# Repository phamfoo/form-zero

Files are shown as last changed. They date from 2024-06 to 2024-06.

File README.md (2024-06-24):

# Form Zero
> Gasket mounted ortholinear keyboard

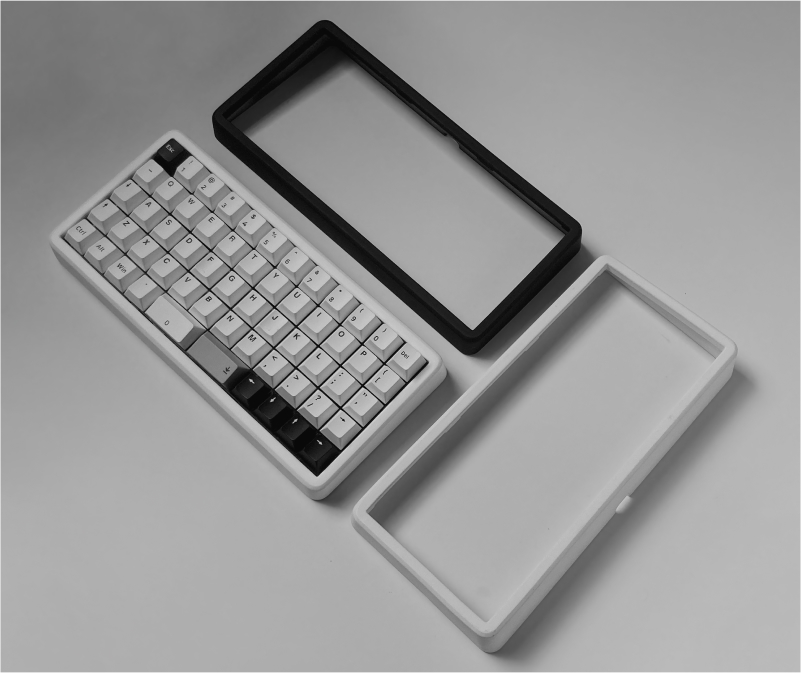
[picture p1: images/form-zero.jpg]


## Introduction
This project aims to provide an ergonomic keyboard that looks nice while also including the neat features that you'd find in custom mechanical keyboards:

- Gasket-mounted.
- Hotswap PCB.
- Clean and minimal design.

It's also designed to be put together by hobbyists, so all the parts can be easily sourced and only basic soldering skills are required.

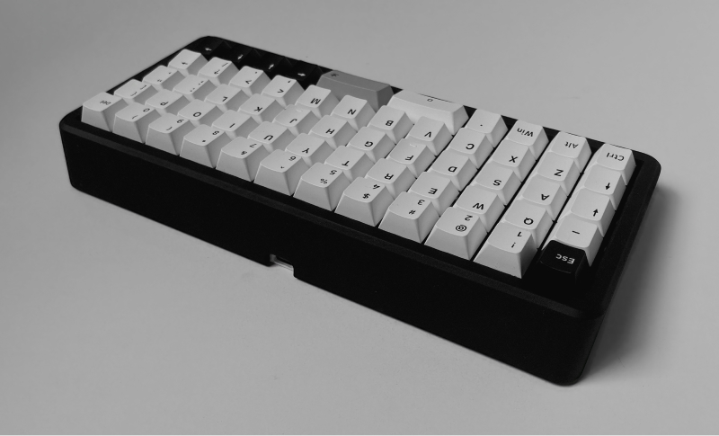
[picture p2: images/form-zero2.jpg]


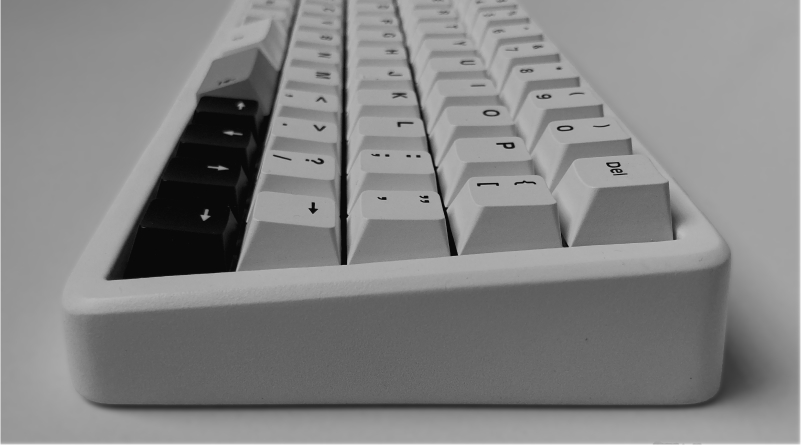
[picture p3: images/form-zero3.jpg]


## Build guide
See [build](/build)

## Thanks
[JLCPCB](https://jlcpcb.com/) for providing the keyboard plate, 3D printed case, and PCBs for this project. If you're looking to build your own board, I highly recommend their services.

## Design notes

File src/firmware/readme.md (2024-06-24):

# form_zero

form_zero

*A short description of the keyboard/project*

* Keyboard Maintainer: [Tien Pham](https://github.com/phamfoo)
* Hardware Supported: *The PCBs, controllers supported*
* Hardware Availability: *Links to where you can find this hardware*

Make example for this keyboard (after setting up your build environment):

    make form_zero:default

Flashing example for this keyboard:

    make form_zero:default:flash

See the [build environment setup](https://docs.qmk.fm/#/getting_started_build_tools) and the [make instructions](https://docs.qmk.fm/#/getting_started_make_guide) for more information. Brand new to QMK? Start with our [Complete Newbs Guide](https://docs.qmk.fm/#/newbs).

## Bootloader

Enter the bootloader in 3 ways:

* **Bootmagic reset**: Hold down the key at (0,0) in the matrix (usually the top left key or Escape) and plug in the keyboard
* **Physical reset button**: Briefly press the button on the back of the PCB - some may have pads you must short instead
* **Keycode in layout**: Press the key mapped to `QK_BOOT` if it is available

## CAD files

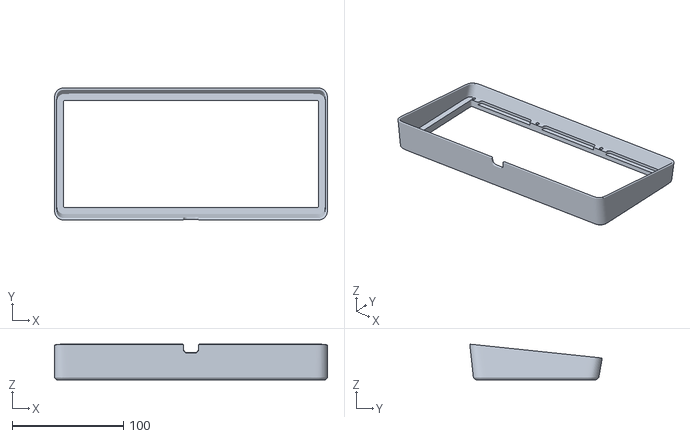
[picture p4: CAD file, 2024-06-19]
build/cases/fdm-top-case.stl
245.7 x 119.1 x 32.1

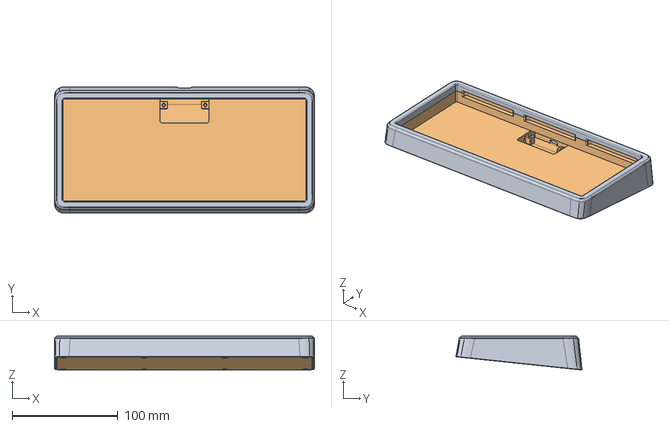
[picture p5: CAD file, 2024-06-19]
src/cases/resin-case.step
245.6 x 119.1 x 32.1 mm

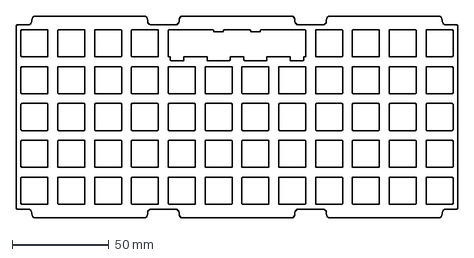
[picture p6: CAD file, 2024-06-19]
src/plates/plate.dxf
228.6 x 104.3 mm

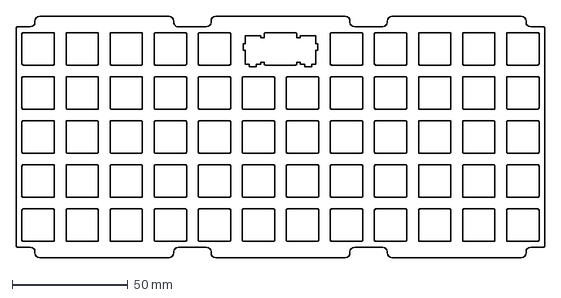
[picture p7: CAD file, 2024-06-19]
src/plates/plate-59.dxf
228.6 x 104.3 mm

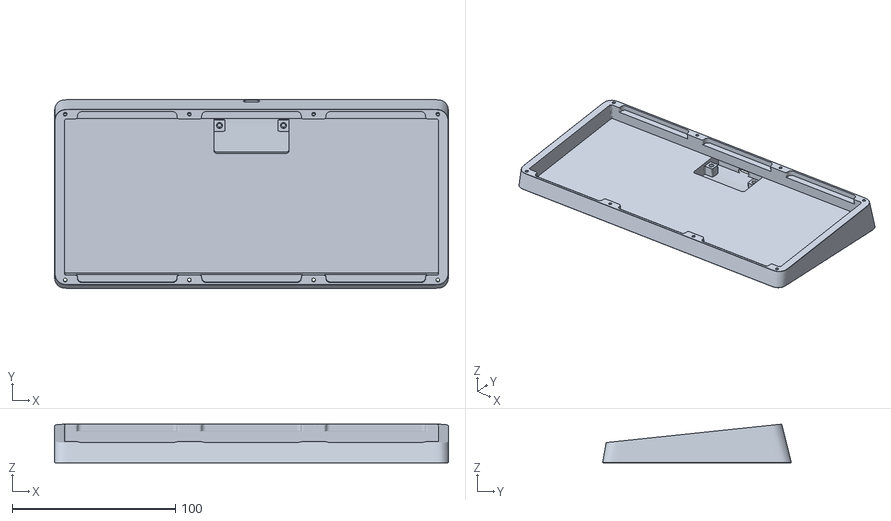
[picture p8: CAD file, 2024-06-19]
build/cases/resin-bottom-case.stl
241.6 x 115.7 x 23.7

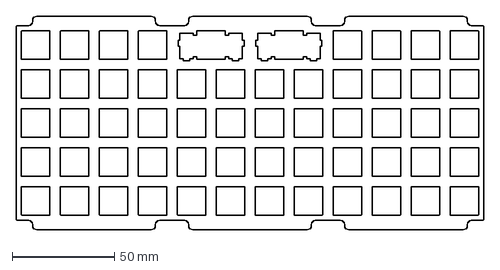
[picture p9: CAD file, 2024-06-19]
src/plates/plate-58.dxf
228.6 x 104.3 mm

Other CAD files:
build/cases/resin-top-case.stl
src/cases/fdm-case.step
build/cases/fdm-bottom-case.stl

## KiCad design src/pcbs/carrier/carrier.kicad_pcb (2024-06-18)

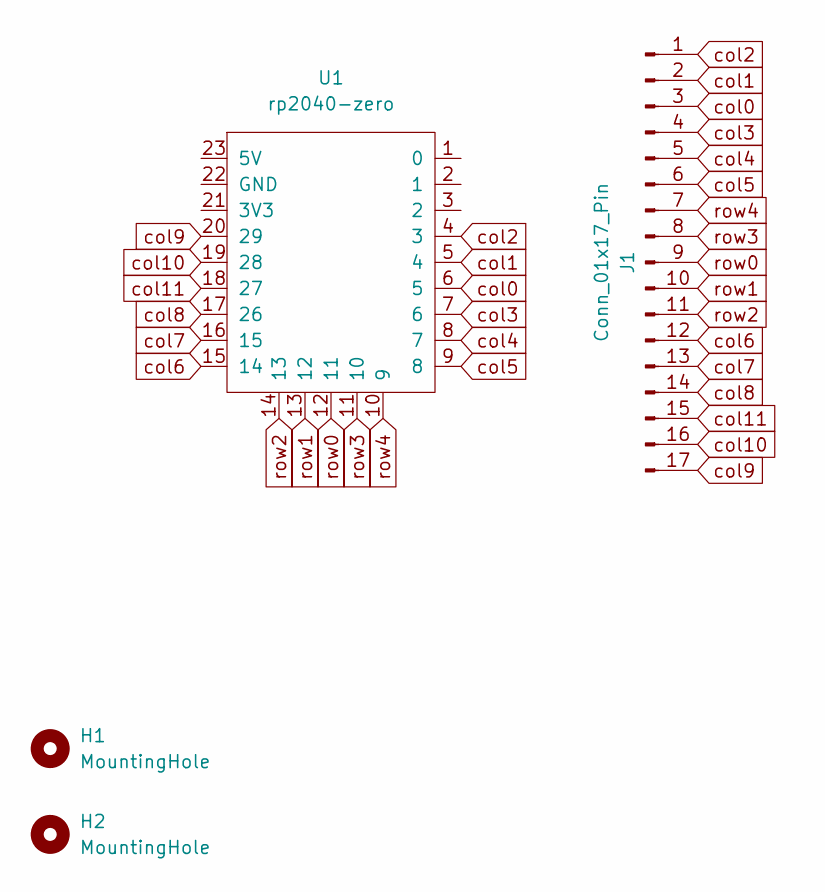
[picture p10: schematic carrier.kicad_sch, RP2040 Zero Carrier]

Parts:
H1, H2: MountingHole; MountingHole_2.2mm_M2
J1: Conn_01x17_Pin; PinHeader_1x17_P2.54mm_Vertical
U1: rp2040-zero; rp2040-zero-tht

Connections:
col0: J1.3, U1.6 (5)
col1: J1.2, U1.5 (4)
col2: J1.1, U1.4 (3)
col3: J1.4, U1.7 (6)
col4: J1.5, U1.8 (7)
col5: J1.6, U1.9 (8)
col6: J1.12, U1.15 (14)
col7: J1.13, U1.16 (15)
col8: J1.14, U1.17 (26)
col9: J1.17, U1.20 (29)
col10: J1.16, U1.19 (28)
col11: J1.15, U1.18 (27)
row0: J1.9, U1.12 (11)
row1: J1.10, U1.13 (12)
row2: J1.11, U1.14 (13)
row3: J1.8, U1.11 (10)
row4: J1.7, U1.10 (9)

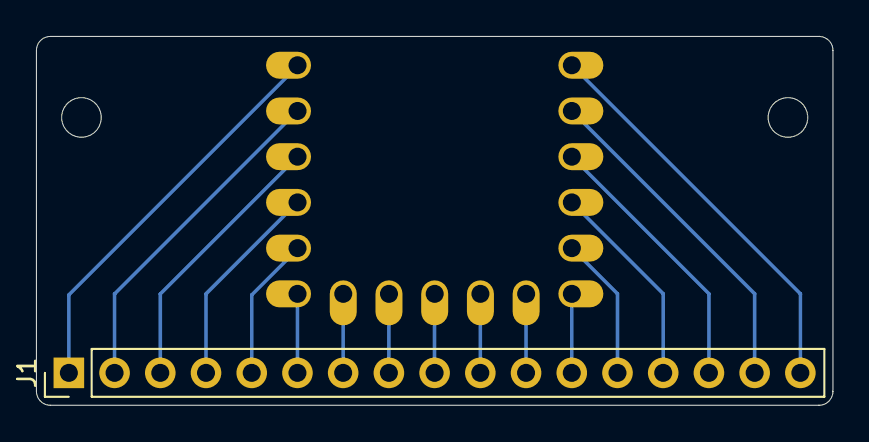
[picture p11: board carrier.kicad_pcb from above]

Board: 2 copper layers, 44.2 x 20.5 mm, 4 parts (1 on the bottom side), 17 nets.

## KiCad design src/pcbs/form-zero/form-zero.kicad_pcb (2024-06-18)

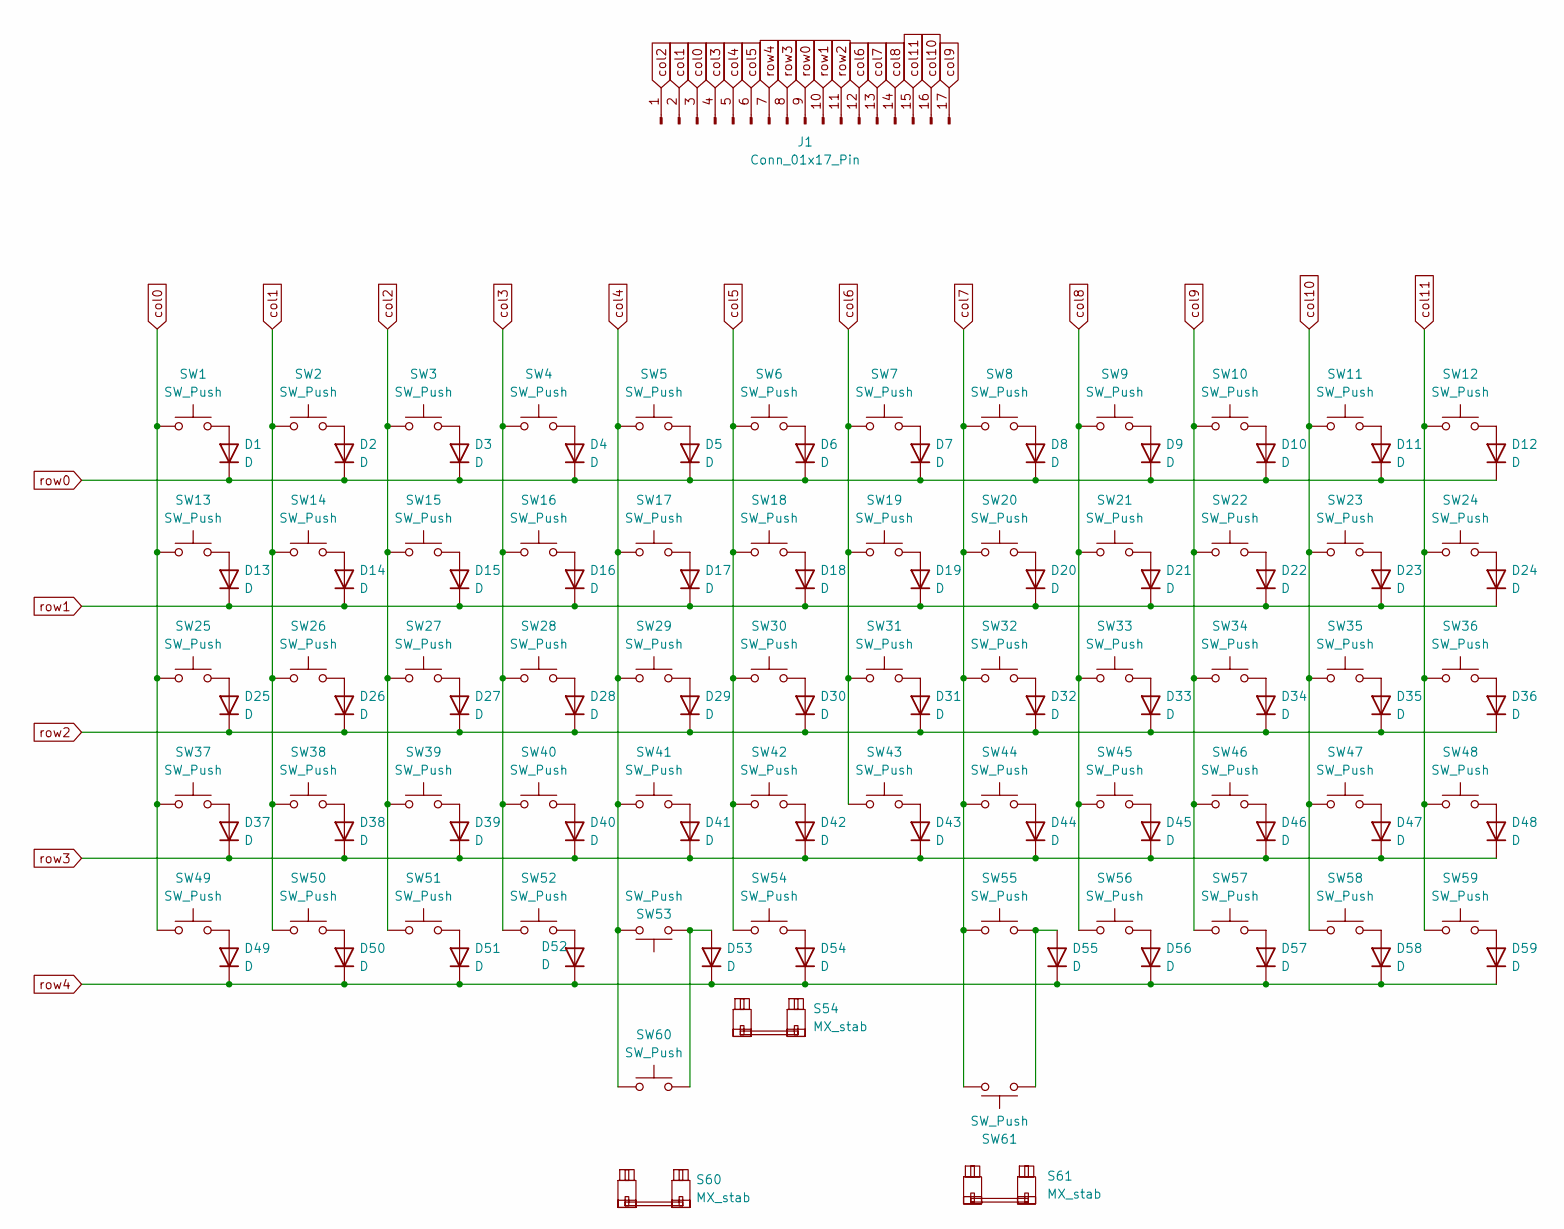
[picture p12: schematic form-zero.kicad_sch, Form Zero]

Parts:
D1, D2, D3, D4, D5, D6, D7, D8, D9, D10, D11, D12, D13, D14, D15, D16, D17, D18, D19, D20, D21, D22, D23, D24, D25, D26, D27, D28, D29, D30, D31, D32, D33, D34, D35, D36, D37, D38, D39, D40, D41, D42, D43, D44, D45, D46, D47, D48, D49, D50, D51, D52, D53, D54, D55, D56, D57, D58, D59: D; D3_TH_SMD_v2
J1: Conn_01x17_Pin; PinHeader_1x17_P2.54mm_Vertical
S54, S60, S61: MX_stab; STAB_MX_2u
SW1, SW2, SW3, SW4, SW5, SW6, SW7, SW8, SW9, SW10, SW11, SW12, SW13, SW14, SW15, SW16, SW17, SW18, SW19, SW20, SW21, SW22, SW23, SW24, SW25, SW26, SW27, SW28, SW29, SW30, SW31, SW32, SW33, SW34, SW35, SW36, SW37, SW38, SW39, SW40, SW41, SW42, SW43, SW44, SW45, SW46, SW47, SW48, SW49, SW50, SW51, SW52, SW53, SW54, SW55, SW56, SW57, SW58, SW59, SW60, SW61: SW_Push; SW_MX_HS_CPG151101S11_1u

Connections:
unnamed: D1.2 (A), SW1.2
unnamed: D2.2 (A), SW2.2
unnamed: D3.2 (A), SW3.2
unnamed: D4.2 (A), SW4.2
unnamed: D5.2 (A), SW5.2
unnamed: D6.2 (A), SW6.2
unnamed: D7.2 (A), SW7.2
unnamed: D8.2 (A), SW8.2
unnamed: D9.2 (A), SW9.2
unnamed: D10.2 (A), SW10.2
unnamed: D11.2 (A), SW11.2
unnamed: D12.2 (A), SW12.2
unnamed: D13.2 (A), SW13.2
unnamed: D14.2 (A), SW14.2
unnamed: D15.2 (A), SW15.2
unnamed: D16.2 (A), SW16.2
unnamed: D17.2 (A), SW17.2
unnamed: D18.2 (A), SW18.2
unnamed: D19.2 (A), SW19.2
unnamed: D20.2 (A), SW20.2
unnamed: D21.2 (A), SW21.2
unnamed: D22.2 (A), SW22.2
unnamed: D23.2 (A), SW23.2
unnamed: D24.2 (A), SW24.2
unnamed: D25.2 (A), SW25.2
unnamed: D26.2 (A), SW26.2
unnamed: D27.2 (A), SW27.2
unnamed: D28.2 (A), SW28.2
unnamed: D29.2 (A), SW29.2
unnamed: D30.2 (A), SW30.2
unnamed: D31.2 (A), SW31.2
unnamed: D32.2 (A), SW32.2
unnamed: D33.2 (A), SW33.2
unnamed: D34.2 (A), SW34.2
unnamed: D35.2 (A), SW35.2
unnamed: D36.2 (A), SW36.2
unnamed: D37.2 (A), SW37.2
unnamed: D38.2 (A), SW38.2
unnamed: D39.2 (A), SW39.2
unnamed: D40.2 (A), SW40.2
unnamed: D41.2 (A), SW41.2
unnamed: D42.2 (A), SW42.2
unnamed: D43.2 (A), SW43.2
unnamed: D44.2 (A), SW44.2
unnamed: D45.2 (A), SW45.2
unnamed: D46.2 (A), SW46.2
unnamed: D47.2 (A), SW47.2
unnamed: D48.2 (A), SW48.2
unnamed: D49.2 (A), SW49.2
unnamed: D50.2 (A), SW50.2
unnamed: D51.2 (A), SW51.2
unnamed: D52.2 (A), SW52.2
unnamed: D53.2 (A), SW53.1, SW60.2
unnamed: D54.2 (A), SW54.2
unnamed: D55.2 (A), SW55.2, SW61.1
unnamed: D56.2 (A), SW56.2
unnamed: D57.2 (A), SW57.2
unnamed: D58.2 (A), SW58.2
unnamed: D59.2 (A), SW59.2
col0: J1.3, SW1.1, SW13.1, SW25.1, SW37.1, SW49.1
col1: J1.2, SW2.1, SW14.1, SW26.1, SW38.1, SW50.1
col2: J1.1, SW3.1, SW15.1, SW27.1, SW39.1, SW51.1
col3: J1.4, SW4.1, SW16.1, SW28.1, SW40.1, SW52.1
col4: J1.5, SW5.1, SW17.1, SW29.1, SW41.1, SW53.2, SW60.1
col5: J1.6, SW6.1, SW18.1, SW30.1, SW42.1, SW54.1
col6: J1.12, SW7.1, SW19.1, SW31.1, SW43.1
col7: J1.13, SW8.1, SW20.1, SW32.1, SW44.1, SW55.1, SW61.2
col8: J1.14, SW9.1, SW21.1, SW33.1, SW45.1, SW56.1
col9: J1.17, SW10.1, SW22.1, SW34.1, SW46.1, SW57.1
col10: J1.16, SW11.1, SW23.1, SW35.1, SW47.1, SW58.1
col11: J1.15, SW12.1, SW24.1, SW36.1, SW48.1, SW59.1
row0: D1.1 (K), D2.1 (K), D3.1 (K), D4.1 (K), D5.1 (K), D6.1 (K), D7.1 (K), D8.1 (K), D9.1 (K), D10.1 (K), D11.1 (K), D12.1 (K), J1.9
row1: D13.1 (K), D14.1 (K), D15.1 (K), D16.1 (K), D17.1 (K), D18.1 (K), D19.1 (K), D20.1 (K), D21.1 (K), D22.1 (K), D23.1 (K), D24.1 (K), J1.10
row2: D25.1 (K), D26.1 (K), D27.1 (K), D28.1 (K), D29.1 (K), D30.1 (K), D31.1 (K), D32.1 (K), D33.1 (K), D34.1 (K), D35.1 (K), D36.1 (K), J1.11
row3: D37.1 (K), D38.1 (K), D39.1 (K), D40.1 (K), D41.1 (K), D42.1 (K), D43.1 (K), D44.1 (K), D45.1 (K), D46.1 (K), D47.1 (K), D48.1 (K), J1.8
row4: D49.1 (K), D50.1 (K), D51.1 (K), D52.1 (K), D53.1 (K), D54.1 (K), D55.1 (K), D56.1 (K), D57.1 (K), D58.1 (K), D59.1 (K), J1.7

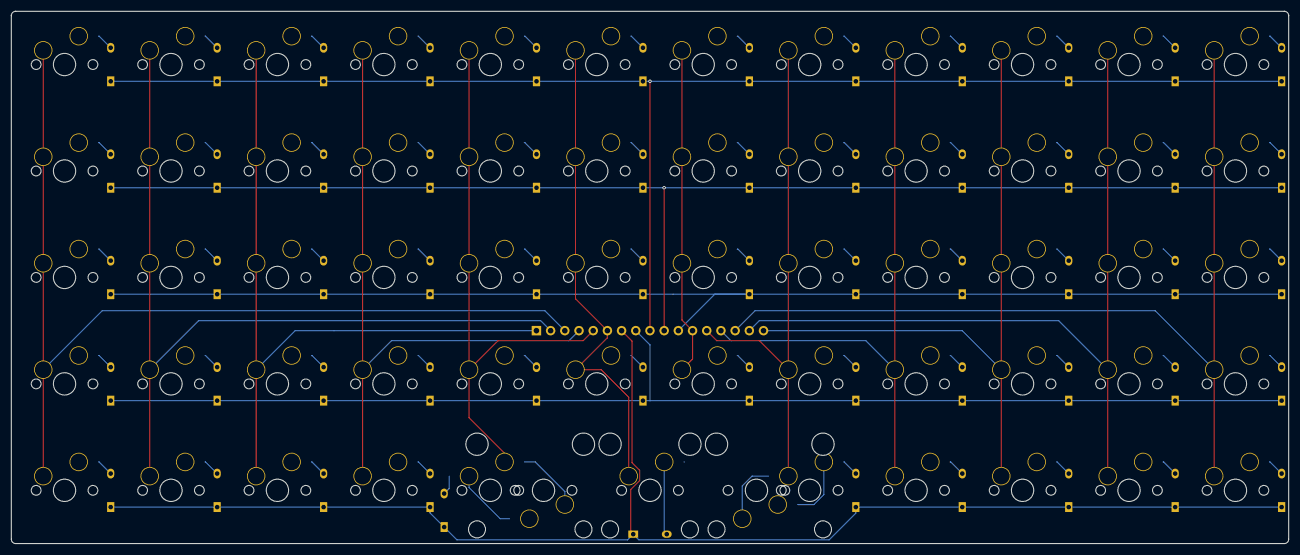
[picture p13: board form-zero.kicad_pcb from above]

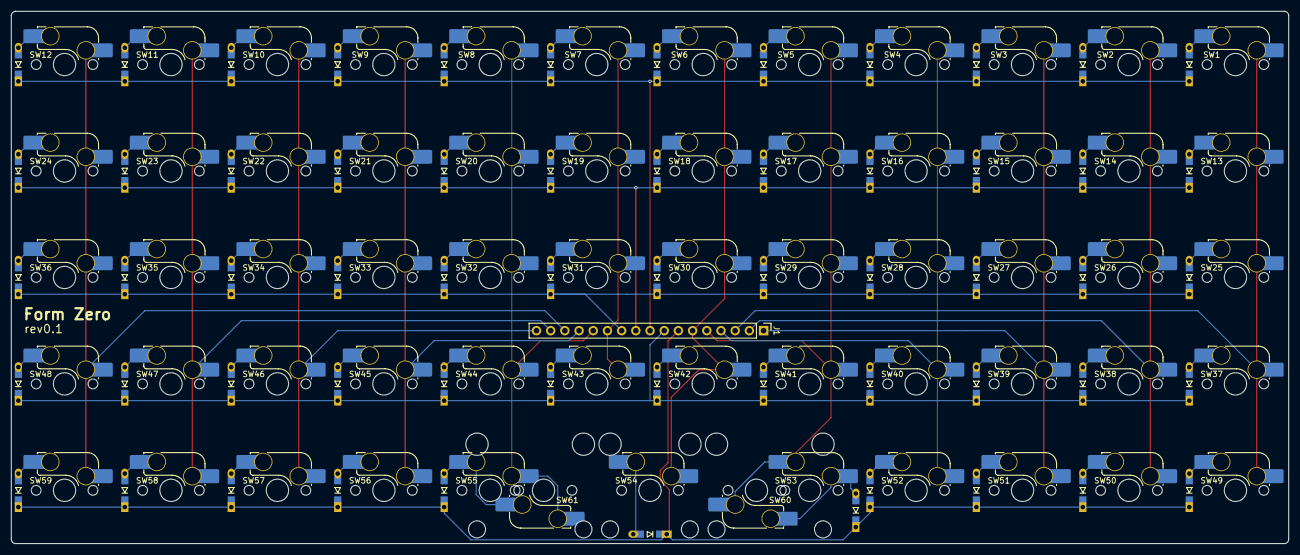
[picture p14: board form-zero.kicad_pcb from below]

Board: 2 copper layers, 228.6 x 95.2 mm, 124 parts (121 on the bottom side), 76 nets.

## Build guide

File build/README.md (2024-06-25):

# Build Guide
Please open an issue if you have any questions.

# The parts
I've included links to purchase some of the parts needed for this build. They're all non-affiliate links.

- [3D printed case](cases)
- 1 x RP2040 Zero
- [PCBs](pcbs)
    - There's a main PCB and a carrier board for the RP2040 Zero.
- Flexstrip jumper cables
    - 2.54mm pitch, 80-100mm length.
    - You'll need enough wires to connect the 17 pins on the main PCB and the carrier board.
    - You can find these on farnell or newark (if you're from NA). There's also [an option](https://www.aliexpress.com/item/1005003498734969.html) on aliexpress.
- 10 x M2 heat set inserts
    - [These inserts](https://www.aliexpress.com/item/1005003582355741.html) should work.
    - Select these options: `M2(OD 3.5mm)` and `Length 3mm`.
- 10 x M2x6mm screws
- 58-61 x kailh hotswap sockets
- 60 x 1N4148 diodes
    - The PCB supports both through hole and SMD diodes.
- [Plate](plates)
- Poron gaskets
    - If you want the gaskets to fit the case perfectly, buy these [D65 gaskets](https://www.aliexpress.com/item/1005004488920878.html).
    - Smaller gaskets should also work, as long as they provide enough tension to securely hold the plate in place. **Just make sure the gaskets are 3mm thick.**

# Build the board
## Install the heat set inserts
You'll need to install 8 of them on the top case and 2 on the bottom case, where the carrier board is mounted.

If you have the resin case, use super glue to hold the inserts in place.

## Solder the parts
Start by soldering the hotswap sockets. The PCB supports 2 layouts. For the bottom row, you can either go with one or two 2u keys in the middle.

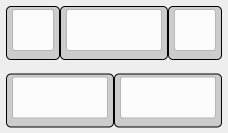
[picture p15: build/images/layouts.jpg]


Keep in mind that if you're using screw-in stabs, one of the screws from the 59-key layout will interfere with SW61 (from the 58-key layout). If that's the case, pick one of the supported layouts and only solder the hotswap sockets for that layout.

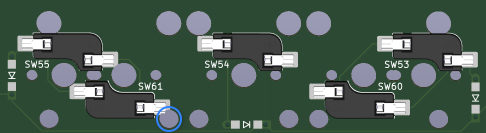
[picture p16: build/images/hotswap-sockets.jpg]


If not, you can solder all 61 sockets onto the PCB instead.

Next, solder the diodes. I recommend using through-hole diodes, as they are much easier to work with than the SMD ones.

Then, solder the RP2040 Zero onto the carrier board using pin headers.

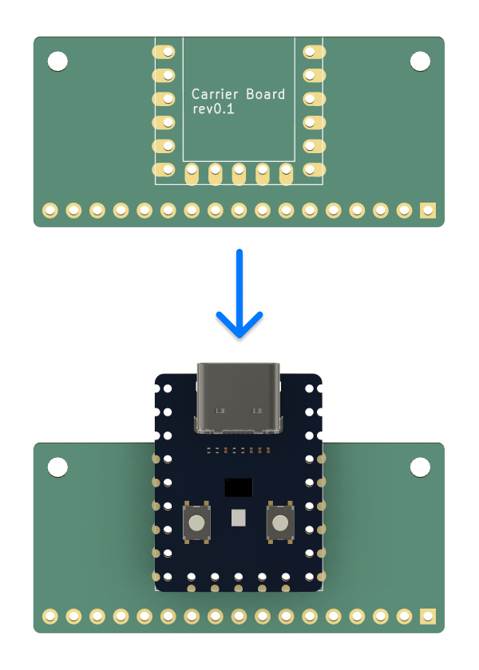
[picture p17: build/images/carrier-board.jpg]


### Connect the PCBs
The two PCBs are connected using flat jumper cables. Start by soldering the wires to connect the boards.

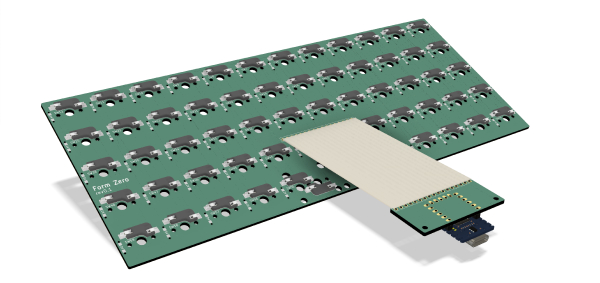
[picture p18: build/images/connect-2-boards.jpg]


### Bend the cable

Unlike FFC/FPC cables, the flexstrip cables used to connect the two boards are easy to solder but not very flexible. Before installing the switches and assembling the board, you'll need to bend it at the right place to ensure everything fits properly.

The end result should look something like this:

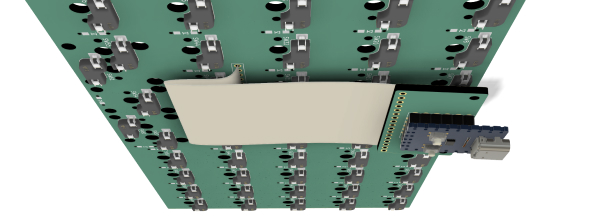
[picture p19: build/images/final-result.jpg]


First thing to do is screw the carrier board to the bottom case.

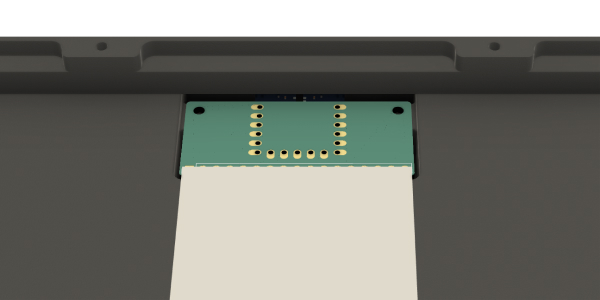
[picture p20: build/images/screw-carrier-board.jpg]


Next, align the PCB's top edge with the top wall of the case. Hold the top edge in place while slowly pushing the bottom edge down to create a soft fold. Then, press the entire board down until it reaches the bottom of the case.

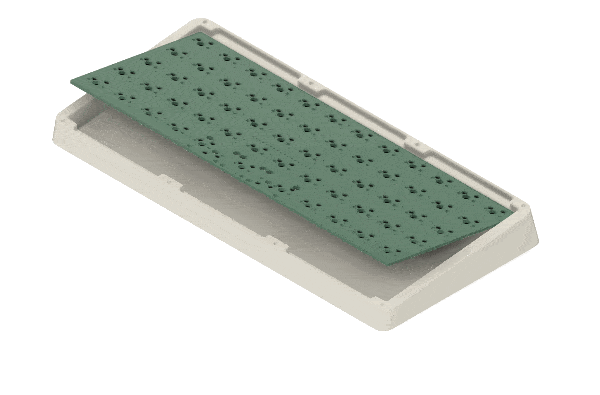
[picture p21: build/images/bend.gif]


The cable's now ready. Unscrew the carrier board to install the switches.

## Install the switches
The board doesn't come with standoffs, so it might be a little tricky to install the switches. Watch [this video](https://www.youtube.com/watch?v=MtzzKFZqiPw&t=303s) if you're not sure how to do it properly.

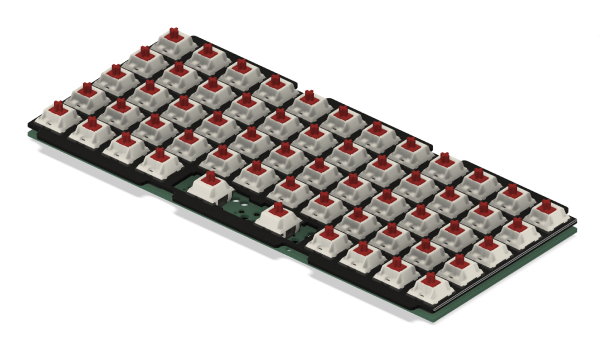
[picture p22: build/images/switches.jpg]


I also highly recommend performing the PE foam mod and tape mod at this step. From my experience, these two mods greatly improve the sound of the board.

## Install the gaskets

Install the gaskets (4x60mm) on the top and bottom case (there are 12 in total).

> If you plan to swap out the top case, install them on the plate instead.

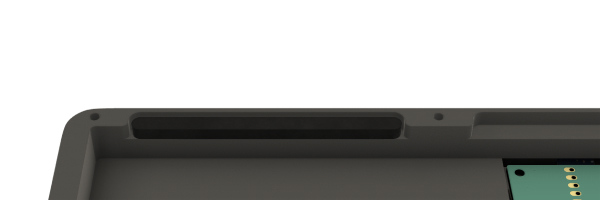
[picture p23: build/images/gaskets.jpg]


Smaller gaskets should also work.

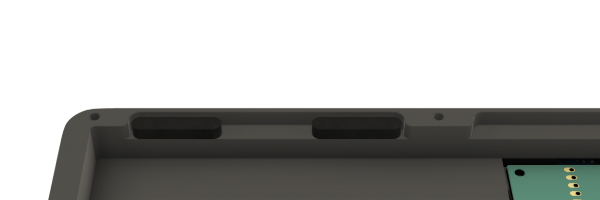
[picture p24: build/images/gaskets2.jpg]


Here's what it looks like with the plate sandwiched between them.

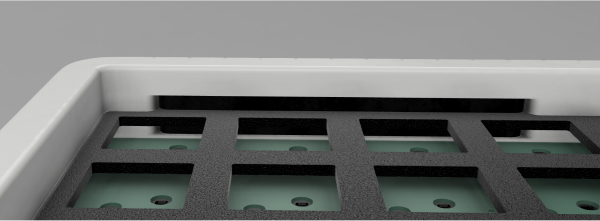
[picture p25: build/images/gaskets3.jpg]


## Assemble the board

The rest is simple. Just screw in the carrier board and the top case. You're done!

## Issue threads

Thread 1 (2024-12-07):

Stuck keys issue

happenslol, 2024-12-07:
Hey, first of all thanks so much for making this keyboard open source!

I've built my own version of this, and I've been having an issue that I can't really explain, so I'm trying to find anyone who might have an idea on what it could be. I realize this might not even be an issue with this keyboard specifically, but I haven't ruled that out yet so I figured asking here wouldn't hurt.

From time to time (I'd say every 1-2 hours), a single key on the keyboard gets stuck and repeats for a few seconds, as if held down. It's definitely not a switch issue, since it's happened with 2 different form-zeros I've built, with different switches, PCBs and controllers. Could it be an issue with the driver or the PCB wiring?

Please feel free to close this if you're not looking to provide any support here. I'm just trying all avenues since I can't figure out what's causing it, and it's slowly driving me insane 😅

phamfoo, 2024-12-08:
The PCB is just a simple matrix connected to the GPIO pins of the RP2040 Zero, so I don't think that's the issue. Could be a firmware issue, have you tried building the firmware yourself with the latest version of qmk?

happenslol, 2024-12-08:
> The PCB is just a simple matrix connected to the GPIO pins of the RP2040 Zero, so I don't think that's the issue.

Yeah, I figured as much. I would also expect very different behavior if it was something like a damaged trace.

> Could be a firmware issue, have you tried building the firmware yourself with the latest version of qmk?

Yeah, I'm on the latest qmk version, and I'm pretty much always compiling the firmware myself since I have custom keymaps.

My prime suspect right now is the USB hub I'm using. Still weird that it's only happening on windows as far as I an tell. Thanks anyways!

phamfoo, 2024-12-13:
Doesn't look like something I can help with unfortunately. I'm leaving this open in case anyone finds a solution.

happenslol, 2024-12-13:
Thanks for your tips in any case! I'll comment if it turns out that it has anything to to with the board (or in case it doesn't 😅)

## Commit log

2024-06-18 Add pcbs
    [carrier.kicad_pcb, carrier.kicad_sch, form-zero.kicad_pcb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]
2024-06-19 Add case and plate files
    [fdm-case.step, plate-58.dxf, plate-59.dxf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]
2024-06-19 Add build files
    [fdm-bottom-case.stl, fdm-top-case.stl, resin-bottom-case.stl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]
